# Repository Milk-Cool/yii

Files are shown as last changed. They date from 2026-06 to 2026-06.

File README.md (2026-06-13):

# yii
tomodachi life-style mii dolls with esp32's inside that can speak to each other via BLE and TTS!

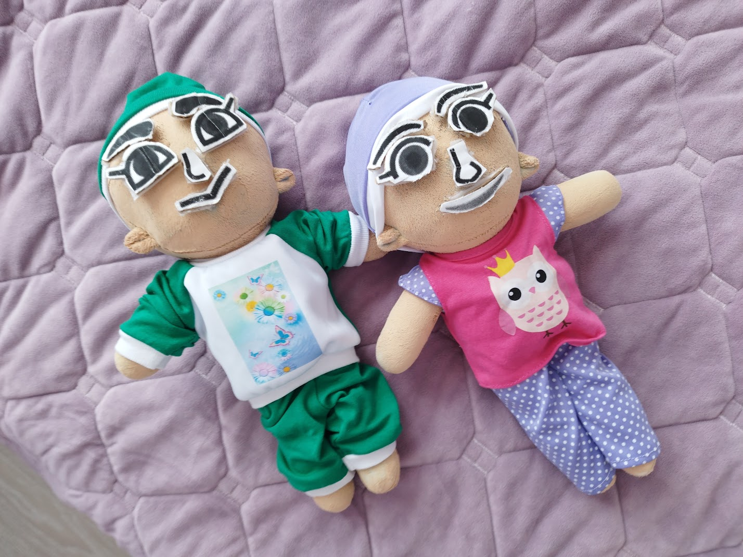
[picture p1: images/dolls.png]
dolls


## how do i use it?
first, you need to build the dolls!! you can find the pcb files and the schematic under the `kicad/` directory, or you can take a look at them here:

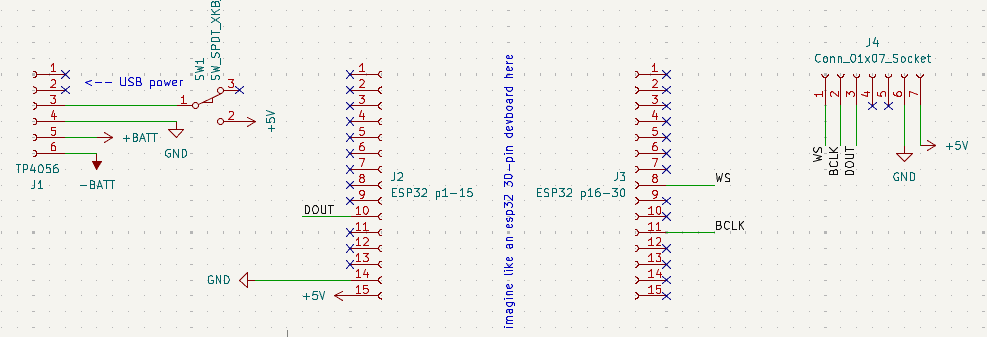
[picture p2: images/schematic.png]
schematic

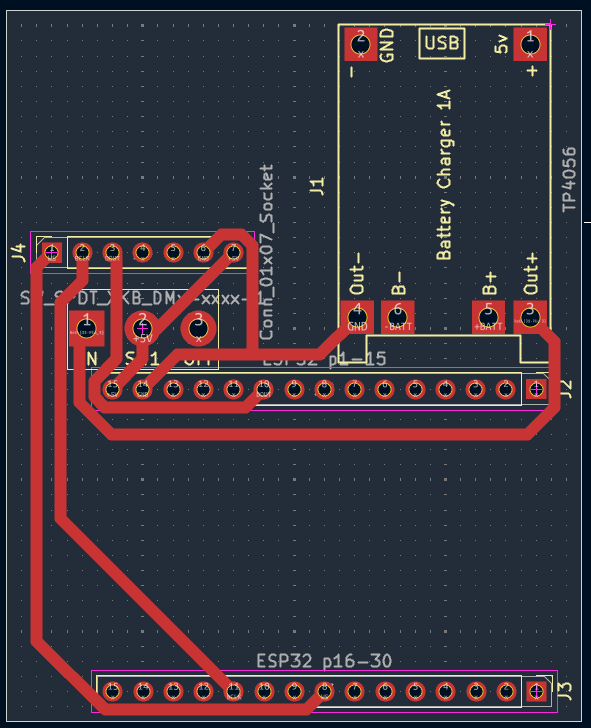
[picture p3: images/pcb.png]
pcb


note that even though i'd recommend a pcb, it's not really necessary to use a pcb since all the components are held together by plush anyway. you can also see a list of components in `bom.csv`.\
as for the dolls themselves, go creative! i found [these on aliexpress](https://www.aliexpress.us/item/3256811798258951.html), and dyed them with fabric paint. i also glued on velcro with fabric glue for attaching the facial features (`face/` for files to be printed), and used a zip locker so that i can open and close them to take components out when needed.

after you're done with the physical part, install the firmware on your esp32's (can be found in `firmware/`)
you can use the [online tool](https://milk-cool.github.io/yii/) to set up the dolls' name and wifi password via usb, then connect via wifi, set voice parameters and reboot to doll mode! (note: if anything goes wrong and the dolls end up bricked, you can erase the flash with esptool, google it)

as for the remote, you're gonna need a plain esp32 board. just flash it with the same firmware and set it up like you'd set up a doll, but reboot it to control mode instead. then, using the online tool, you can control your dolls (poke, feed, and play with them).

## what does it do?
there's a lot of stuff you can do with the dolls, but the most important one is watching them!! if you get two or more of them, you can watch them talk to each other. they'll develop a friendship and maybe even a romantic relationship eventually! (note: there's no gender/romantic preferences system here, everyone's attracted to everyone)

other than that, you can feed them with the remote, poke them, or play games with them. you can also track their progress and their XP as they talk to others more and more.

## why does this exist?
i was a really big fan of tomodachi life ever since i learned about the first game, and i thought i might want to bring the concept of miis to life!! and so i did :D

it's nowhere near as good, obviously, but i'm happy with the result

## credits
1p2t kicad library: https://github.com/BrianLeishman/jrgbwww24/blob/master/1P2T%20SPDT.kicad_mod
tp4056 kicad library: https://github.com/ccadic/TP4056-18650

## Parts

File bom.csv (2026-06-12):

Product name | Product link | Product cost | Product amount | Notes
ESP32 DevKitV1 | https://www.aliexpress.us/item/3256809960927549.html | $5.79 | 1
MAX98357A i2s audio amplifier | https://www.aliexpress.us/item/3256806817487911.html | $4.53 | 1
3W 4Ohm speaker | https://www.aliexpress.us/item/3256809207290559.html | $3.46 | 1
1x7 pin headers | https://nl.aliexpress.com/item/4001198421663.html | $0.18 | 1 | Link leads to listing with 10 pieces available only. Price specified per unit; it is $1.79 to buy 10 pcs.
1x15 pin headers | https://nl.aliexpress.com/item/4001198421663.html | $0.21 | 2 | Link leads to listing with 10 pieces available only. Price specified per unit; it is $2.14 to buy 10 pcs.
TP4056 power supply module | https://www.aliexpress.us/item/3256806796593467.html | $1.77 | 1
1P2T switch | https://www.aliexpress.us/item/3256809760123375.html | $0.10 | 1 | Link leads to listing with 20 pieces available only. Price specified per unit; it is $2.00 to buy 20 pcs.
800 mAh lithium-ion battery | https://www.aliexpress.us/item/3256809268727485.html | $5.90 | 1
Total |  | $21.94

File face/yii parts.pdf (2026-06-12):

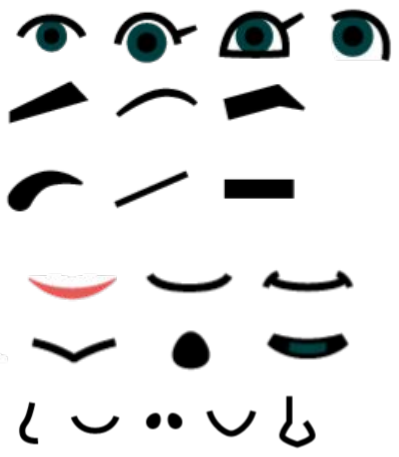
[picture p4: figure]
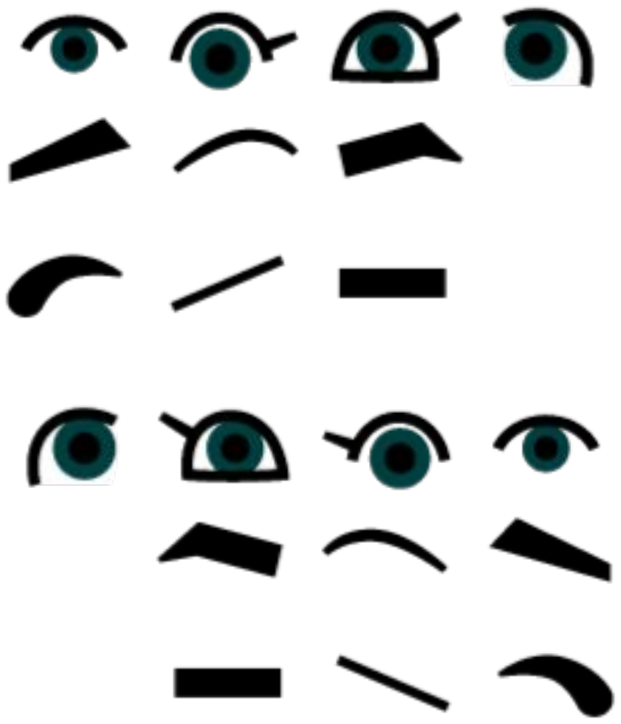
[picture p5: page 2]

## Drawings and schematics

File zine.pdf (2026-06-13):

## Yii -- talking Mii-like plush dolls!

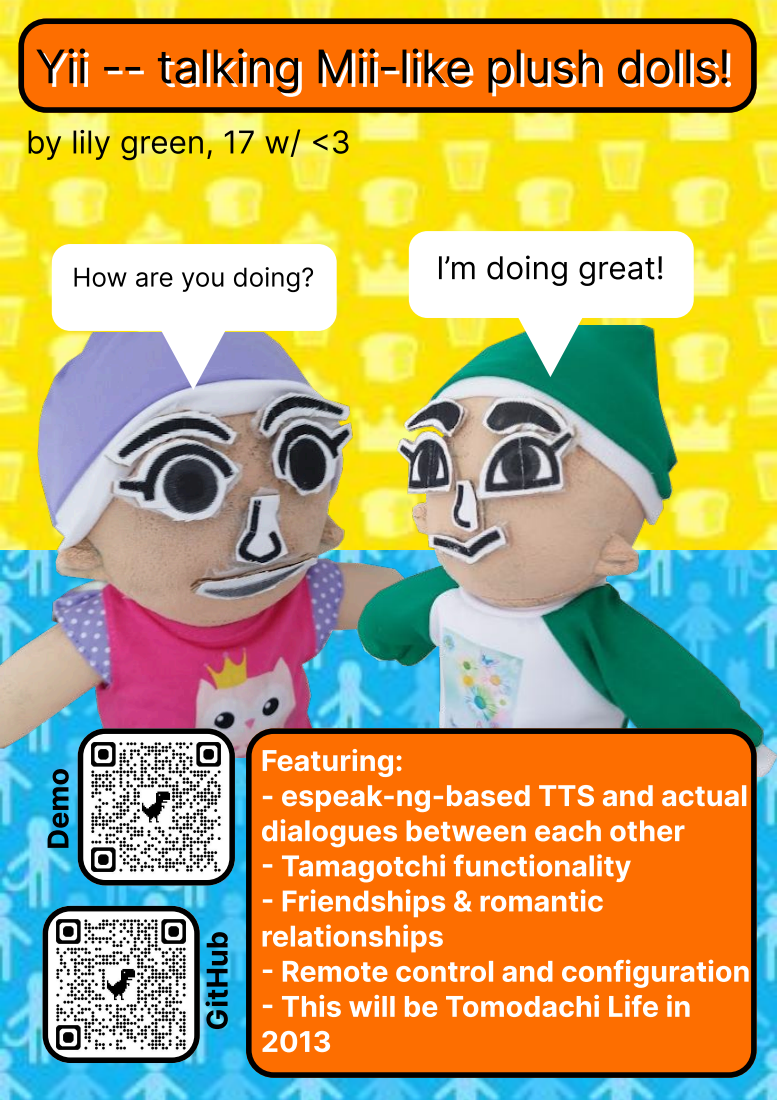
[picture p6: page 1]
How are you doing?; I’m doing great!; Demo; GitHub

by lily green, 17 w/ <3

Featuring:
- espeak-ng-based TTS and actual
dialogues between each other
- Tamagotchi functionality
- Friendships & romantic
relationships
- Remote control and configuration
- This will be Tomodachi Life in

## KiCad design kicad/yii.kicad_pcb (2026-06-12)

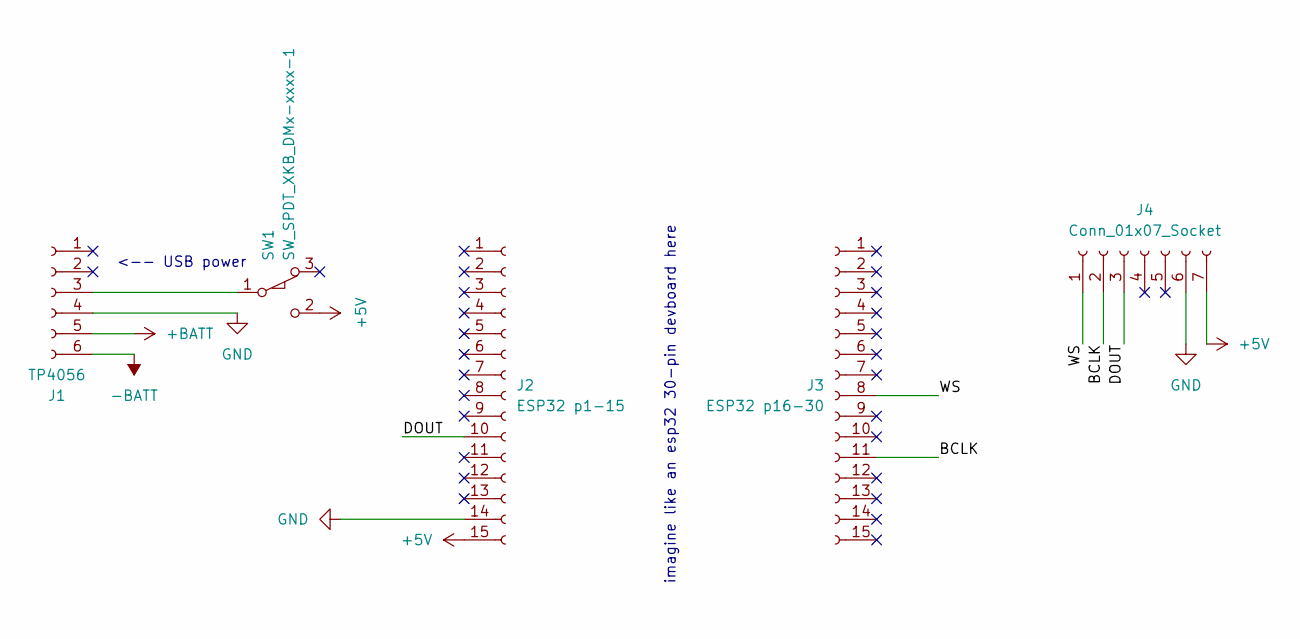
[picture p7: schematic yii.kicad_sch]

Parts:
J1: TP4056; TP4056-18650
J2: ESP32 p1-15; PinHeader_1x15_P2.54mm_Vertical
J3: ESP32 p16-30; PinHeader_1x15_P2.54mm_Vertical
J4: Conn_01x07_Socket; PinSocket_1x07_P2.54mm_Vertical
SW1: SW_SPDT_XKB_DMx-xxxx-1; 1p2t

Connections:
+5V: J2.15, J4.7, SW1.2 (B)
+BATT: J1.5
-BATT: J1.6
/BCLK: J3.11, J4.2
/DOUT: J2.10, J4.3
/WS: J3.8, J4.1
GND: J1.4, J2.14, J4.6
unnamed: J1.3, SW1.1 (A)

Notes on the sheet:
<-- USB power
imagine like an esp32 30-pin devboard here

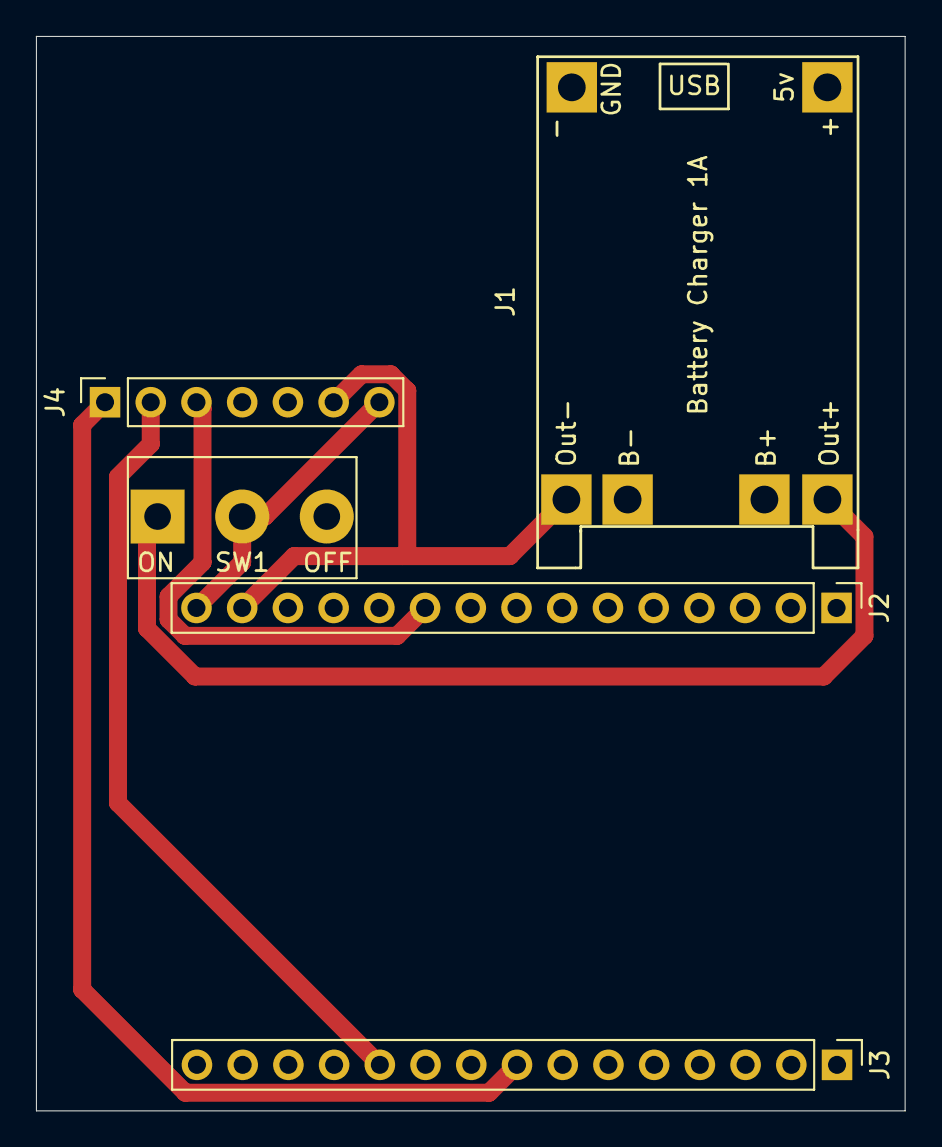
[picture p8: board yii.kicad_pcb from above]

Board: 2 copper layers, 48.3 x 59.7 mm, 5 parts (0 on the bottom side), 6 nets.

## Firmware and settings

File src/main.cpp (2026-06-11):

#include <Arduino.h>
#include "bus.h"
#include "storage.h"
#include "blecomm.h"
#include "state.h"
#include "control.h"
#include "random.h"
#include "tts.h"
#include <WiFi.h>
#include <WebServer.h>
#include <ESPmDNS.h>
#include <DNSServer.h>
#include <ArduinoJson.h>
#include <ElegantOTA.h>

WebServer server(80);
IPAddress ip_self(192, 168, 121, 1);
IPAddress ip_mask(255, 255, 255, 0);
DNSServer dnsServer;

static uint8_t mode;
static bool setup_write = false;

extern const uint8_t config_html_start[] asm("_binary_res_config_html_start");

String redirect_from[] = {
    "/",
    "/generate_204",
    "/fwlink",
    "/check_network_status.txt",
    "/ncsi.txt",
    "/connecttest.txt",
    "/redirect",
    "/hotspot-detect.html",
    "/library/test/success.html",
    "/success.txt",
    "/canonical.html",
};
String not_found_from[] = {
    "/wpad.dat",
    "/favicon.ico",
    "/chat/favicon.ico",
};

void setup() {
    Serial.begin(115200);
    Serial.println("i'm alive!!");
    storage_init();
    mode = storage().getUChar("mode", 0); // 0 - setup, 1 - control, 2 - doll
    if(mode == 2) {
        tts_init();
        random_init();
        ble_init();
        state_init();
        ble_set_cb(state_handle_advertisement);

        tts_play("ah!");
    } else if(mode == 1) {
        ble_init();
        control_init();
        ble_set_cb(control_handle_advertisement);
    } else if(mode == 0) {
        pinMode(2, OUTPUT);
        digitalWrite(2, HIGH);

        if(storage().getString("password") != "") {
            WiFi.softAPConfig(ip_self, ip_self, ip_mask);
            WiFi.softAP("config - " + storage().getString("name", "unnamed"), storage().getString("password"));
            IPAddress ip = WiFi.softAPIP();
            dnsServer.start(53, "*", ip);

            server.on("/config", HTTP_GET, []() {
                if(server.hasArg("get")) {
                    JsonDocument doc;
                    
                    doc["name"] = storage().getString("name");
                    doc["pitch_base"] = storage().getUChar("pitch_base");
                    doc["pitch_range"] = storage().getUChar("pitch_range");
                    doc["flutter"] = storage().getUChar("flutter");
                    doc["speed"] = storage().getUChar("speed");
                    doc["tone1"] = storage().getUChar("tone1");
                    doc["tone2"] = storage().getUChar("tone2");
                    doc["tone3"] = storage().getUChar("tone3");
                    doc["gain"] = storage().getUChar("gain");

                    String out;
                    serializeJson(doc, out);
                    server.send(200, "text/plain", out);
                }
                server.send(200, "text/html", (const char*)config_html_start);
            });

            server.on("/config", HTTP_POST, []() {
                String t = server.arg("t");
                if(t == "control") {
                    storage().putUChar("mode", 1);
                    ESP.restart();
                } else if(t == "doll") {
                    storage().putUChar("mode", 2);
                    ESP.restart();
                } else if(t == "rmet") {
                    storage().remove("met");
                    ESP.restart();
                }
                String name = server.arg("name");
                String value = server.arg("value");
                if(!t || !name || (t != "reset" && !value)) {
                    server.send(400, "text/plain", "bad request");
                }
                if(t == "string") storage().putString(name.c_str(), value);
                else if(t == "u8") storage().putUChar(name.c_str(), value.toInt());
                else if(t == "u16") storage().putUShort(name.c_str(), value.toInt());
                else if(t == "u32") storage().putUInt(name.c_str(), value.toInt());
                else if(t == "reset") storage().remove(name.c_str());
                server.send(200, "text/html", (const char*)config_html_start);
            });

            for(String path : redirect_from) {
                server.on(path, HTTP_GET, []() {
                    server.sendHeader("Location", "/config", true);
                    server.send(302, "text/plain", "");
                });
            }
            for(String path : not_found_from)
                server.on(path, HTTP_GET, []() { server.send(404); });
            server.onNotFound([]() {
                server.sendHeader("Location", "/config", true);
                server.send(302, "text/plain", "");
            });
            
            ElegantOTA.begin(&server);
            server.begin();
        }
    }
}

// potential loss with consecutive packets but I DON'T CARE !!
static std::vector<uint8_t> data;
static BusData out_data;
static bool get_serial_data() {
    while(Serial.available()) {
        int b = Serial.read();
        if(b == -1) continue;
        data.push_back(b);
    }
    if(bus_is_complete(data)) {
        out_data = bus_parse(data);
        return true;
    }
    return false;
}
static void reset_serial_data() {
    data.erase(data.begin(), data.end());
    out_data.erase(out_data.begin(), out_data.end());
}

static uint64_t boot_held_since;
static bool boot_held = false;
void loop() {
    if(mode == 0) {
        if(get_serial_data()) {
            BusData out;
            for(BusEntry& ent : out_data) {
                if(ent.val.type == TYPE_NAME) continue; // something is wrong
                if(ent.name == "!setup_write" && ent.val.type == TYPE_U8) {
                    setup_write = ent.val.u;
                    continue;
                }
                if(setup_write) {
                    if(ent.val.type == TYPE_STR) storage().putString(ent.name.c_str(), ent.val.str);
                    else if(ent.val.type == TYPE_U8) storage().putUChar(ent.name.c_str(), ent.val.u);
                    else if(ent.val.type == TYPE_U16) storage().putUShort(ent.name.c_str(), ent.val.u);
                    else if(ent.val.type == TYPE_U32) storage().putUInt(ent.name.c_str(), ent.val.u);
                    else if(ent.val.type == TYPE_RESET) storage().remove(ent.name.c_str());
                }
                if(ent.val.type == TYPE_STR) out.push_back((BusEntry){ .name = ent.name, .val = { .type = TYPE_STR, .str = storage().getString(ent.name.c_str()) } });
                else if(ent.val.type == TYPE_U8) out.push_back((BusEntry){ .name = ent.name, .val = { .type = TYPE_U8, .u = storage().getUChar(ent.name.c_str()) } });
                else if(ent.val.type == TYPE_U16) out.push_back((BusEntry){ .name = ent.name, .val = { .type = TYPE_U16, .u = storage().getUShort(ent.name.c_str()) } });
                else if(ent.val.type == TYPE_U32) out.push_back((BusEntry){ .name = ent.name, .val = { .type = TYPE_U32, .u = storage().getUInt(ent.name.c_str()) } });
                else if(ent.val.type == TYPE_RESET) out.push_back((BusEntry){ .name = ent.name, .val = { .type = TYPE_RESET } });
            }
            if(out.size() > 0) {
                auto bin = bus_compile(out);
                Serial.write(bin.data(), bin.size());
            }
            delay(1);
            reset_serial_data();
        }
        dnsServer.processNextRequest();
        server.handleClient();
        ElegantOTA.loop();
        return;
    }

    // reboot into config mode if GP0 is held for >=3s
    if(digitalRead(0) == LOW) {
        if(!boot_held) {
            boot_held = true;
            boot_held_since = millis();
        }
        if(millis() - boot_held_since >= 3000) {
            storage().putUChar("mode", 0);
            ESP.restart();
        }
    } else boot_held = false;

    if(mode == 1) control_loop();
    else state_loop();
}

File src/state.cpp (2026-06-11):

#include "state.h"
#include <vector>
#include <mutex>
#include <string.h>
#include "storage.h"
#include "blecomm.h"
#include <esp_mac.h>
#include "random.h"
#include "tts.h"
#include "data/data.h"

#define ADVERTISEMENT_LENGTH 31
#define FREE_SPACE_LENGTH (ADVERTISEMENT_LENGTH - 7 - 2) // 7 bytes occupied by other fields, 2 bytes occupied by length and type

#define RESPONSE_TIMEOUT 12000

#define FLAG_HAS_PARTNER (1 << 0)

static std::vector<uint8_t> advertisement;

static char name[13] = { 0 };
static uint8_t activity = 0;
static uint8_t variant = 0;
static uint8_t dialogue = 0;
static uint8_t level = 0;
static uint8_t xp = 0; // 4b
static uint8_t saturation = 0; // 4b
static uint8_t thing = 0;
static uint8_t other_thing = 0;
static uint8_t flags = 0;
static uint8_t special_data[2] = { 0 };

static std::vector<uint8_t> met;

static uint8_t my_mac[6];

static bool speaking = false;
std::mutex upd_mutex;

static void update() {
    Serial.println("adv upd");
    advertisement.erase(advertisement.begin(), advertisement.end());
    
    for(uint8_t i = 0; i < 12; i++) advertisement.push_back(name[i]);
    advertisement.push_back(activity);
    advertisement.push_back(variant);
    advertisement.push_back(dialogue);
    advertisement.push_back(level);
    advertisement.push_back((xp << 4) | saturation);
    advertisement.push_back(thing);
    advertisement.push_back(other_thing);
    advertisement.push_back(flags);
    for(uint8_t i = 0; i < 2; i++) advertisement.push_back(special_data[i]);

    storage().putString("name", name);
    storage().putUChar("level", level);
    storage().putUChar("xp", xp);
    storage().putUChar("saturation", saturation);

    ble_set_data(advertisement, activity != 0);
}

static void update_flags() {
    flags = (storage().getUChar("partner") ? FLAG_HAS_PARTNER : 0);
}

static void inc_xp() {
    if(xp == 15) {
        xp = 0;
        ++level;
    } else xp++;
    storage().putUChar("level", level);
    storage().putUChar("xp", xp);
}

void state_init() {
    std::lock_guard<std::mutex> guard(upd_mutex);
    esp_read_mac(my_mac, ESP_MAC_BT);

    String name_loaded = storage().getString("name", "dummy girl");
    memcpy(name, name_loaded.c_str(), name_loaded.length());

    level = storage().getUChar("level");
    xp = storage().getUChar("xp");
    saturation = storage().getUChar("saturation");

    size_t s = storage().getBytesLength("met");
    if(s > 0) {
        uint8_t d[s];
        storage().getBytes("met", d, s);
        for(size_t i = 0; i < s; i++)
            met.push_back(d[i]);
    }
    update_flags();

    update();
}

int16_t get_met(uint8_t* mac) {
    for(size_t i = 0; i < met.size(); i += 7) {
        if(!memcmp(mac, met.data() + i, 6))
            return met[i + 6];
    }
    return -1;
}
void put_met(uint8_t* mac, uint8_t val) {
    for(size_t i = 0; i < met.size(); i += 7)
        if(!memcmp(mac, met.data() + i, 6)) {
            met[i + 6] = val;
            storage().putBytes("met", met.data(), met.size());
            return;
        }
    for(int i = 0; i < 6; i++)
        met.push_back(mac[i]);
    met.push_back(val);
    storage().putBytes("met", met.data(), met.size());
}

static uint8_t get_cat(const char* str) {
    uint8_t cat = 0;
    String s(str);
    for(uint8_t i = 0; i <= 9; i++)
        if(s.indexOf(String("%") + i) != -1)
            cat = i;
    return cat;
}
static uint8_t get_random_thing(uint8_t cat) {
    uint8_t idx = 0;
    for(uint8_t i = 0; i < cat; i++)
        idx += things[i].size();
    idx += random_get() % things[cat].size();
    return idx;
}
static const char* get_thing(uint8_t idx) {
    uint8_t i = 0;
    while(true) {
        if(idx < things[i].size()) return things[i][idx];
        idx -= things[i].size();
        i++;
    }
    return "";
}
String replace_percents(const char* str, const char* their_name) {
    String o = String(str);
    uint8_t cat = 0;
    for(uint8_t i = 0; i <= 9; i++)
        o.replace(String("%") + i, "");
    o.replace("%n", name);
    o.replace("%N", their_name);
    o.replace("%a", their_name); // TODO: change me when implmenting 3+ dolls
    o.replace("%t", get_thing(thing));
    o.replace("%T", get_thing(other_thing));
    return o;
}

static uint64_t last = 0;
static uint64_t tts_cooldown = 0;
static uint64_t block_until = 0;
static uint64_t activity_reset_timer = 0xffffffff;

static bool check_can_upd(bool* changed) {
    uint64_t now = millis();
    if(now < block_until) return false;
    if(now - tts_cooldown < 400) return false; // race condition fix
    if(speaking && tts_done()) {
        Serial.println("done speaking");
        speaking = false;
        tts_cooldown = now;
        if(changed != NULL) *changed = true;
        if(activity != 0 && dialogue == activities[activity][variant].size() - 1) activity_reset_timer = millis();
        return true;
    }
    if(speaking) return false;
    return true;
}

#define RANDOMIZE_THING thing = get_random_thing(get_cat(activities[activity][variant][dialogue])); \
    do { other_thing = get_random_thing(get_cat(activities[activity][variant][dialogue])); } while(thing == other_thing);
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

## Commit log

2026-04-05 a lot of state fixes + more dialogues
    [state.cpp]
2026-04-05 fix repeated last phrase
    [state.cpp]
2026-04-05 made it reset the dialogue after some time
    [state.cpp]
2026-04-09 they can now confess and become couples lol
2026-06-12 readme, bom, and most of the necessary files
    [bom.csv, yii.kicad_pcb, yii.kicad_sch]
2026-06-12 OOPS miscalculation
    [bom.csv]
